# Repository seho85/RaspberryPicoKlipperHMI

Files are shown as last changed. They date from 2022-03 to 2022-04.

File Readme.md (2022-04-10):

>  **DISCLAIMER:**
>   This project project is made by an hobbyist.
>   Everything described here is without guarantee, so if you perform something described here, **YOU DO IT ON YOUR OWN RISK**
>
ASCII Display for Klipper
=========================

This project contains the ASCII Display that I use with Klipper.

It's controlled by a Rotary Encoder and few Buttons and controllable LEDs.

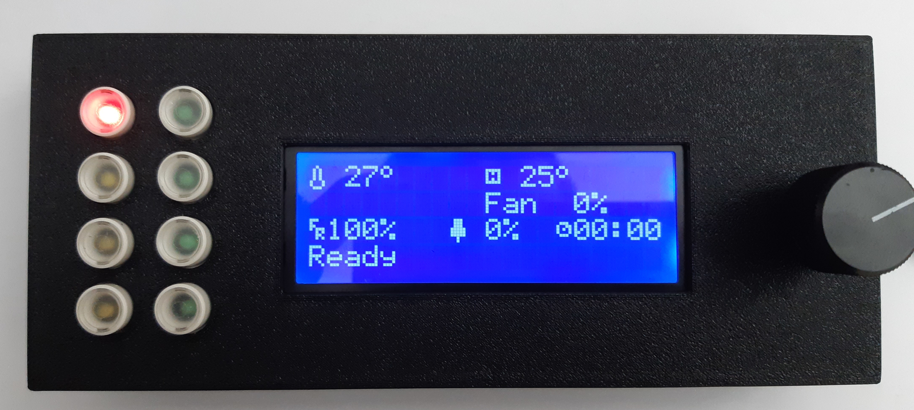
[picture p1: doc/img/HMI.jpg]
HMI


Features:
* Raspberry Pi Pico for easy klipper integration
* 20x4 LCD
  * Controlled by rotary encoder with push button
  * Background LED brightness controllable from klipper
* 8 Pushbuttons for custom actions in klipper
* 7 LEDs triggerable from klipper.
* Single MicroUSB cable for connection to klipper host machine.

See [General](doc/General.md) for details.

KiCAD Projects
--------------
Two KiCAD projects can be found.

* _RPiPicoKlipperAsciiHMI_
  * Schematics I used on my breadboard during "proof of concept" phase.
* _RPiPicoAsciiHMI2_
  * [Schematics](https://github.com/seho85/RaspberryPicoKlipperHMI/raw/master/RPiPicoAsciiHMI2/Schematic.pdf)) for the HMI that I use with klipper.

See [KiCAD Projects](doc/KiCAD_Projects.md)

PCBs
----
Basically the whole HMI consists of two PCBs.

* The [Button PCB](doc/BTN_LED_PCB.md)
    * Buttons (with integrated LEDs)
* The [Main PCB](doc/Main_PCB.md)
  * all other components.

FreeCAD Projects
----------------
In the _FreeCAD_ folder two FreeCAD Projects for the case and the backcover can be found.

Hardware used
-------------
The major components used for the HMI can be found here [Hardware Listing](doc/Hardware.md)

For a complete listing of all the components please refer to the KiCAD Project.

MicroPython
-----------
During the creation process of the HMI I created a few MicroPython scripts to test a components.

See [MicroPython Testing Script](doc/MicroPython.md)

Klipper Configuration
---------------------
See [Klipper Config](doc/klipper_config.md)

How to Flash Raspberry Pi Pico
------------------------------
See [Flashing](doc/Flashing.md)

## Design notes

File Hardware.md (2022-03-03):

Hardware Used
=============

BOM
---
* Potentiometer 10k
* LCD20x04 (HD44780 Compatible)
* Rotary Encoder with Push Button
* RaspberryPi Pico
* diffrent Resistors
* Buttons
* ULN2803A

Where to Buy?
-------------

http://www.berrybase.de

* [Display](https://www.berrybase.de/sensoren-module/displays/alphanumerische-displays/alphanumerisches-lcd-20x4-blau/wei-223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)
* [Raspberry Pi Pico](https://www.berrybase.de/neu/raspberry-pi-pico-rp2040-mikrocontroller-board?number=RPI-PICO&c=2461)
* [ULN2830A](https://www.berrybase.de/bauelemente/aktive-bauelemente/ics/ics-u../uln2803a-npn-darlington-transistor-array-dil-18)
* [Rotary Encoder](https://www.berrybase.de/bauelemente/passive-bauelemente/potentiometer/drehimpulsgeber/drehregler/rotary-encoder-mit-breakoutboard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)
* [Potentiometer](https://www.berrybase.de/bauelemente/passive-bauelemente/potentiometer/drehpotis/drehpotentiometer-10k-937-liegend-mono-6mm-printmontage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)

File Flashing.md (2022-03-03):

How to flash Klipper to Raspberry Pi Pico
=========================================

Build klipper for Raspberry Pi Pico
-----------------------------------
1) Go to klipper directory
2) call _make menuconfig_
3) select
    * Micro-controller Architecture
        * Raspberry PI RP2040
    * Communication Interface
        * USB
    * GPIO Pins to set at micro-controller startup
        * !gpio0,!gpio1,!gpio5,!gpio4,!gpio3,!gpio2
4) save configuration
5) build firmware
    * call _make_
6) file needed for flashing can be found in
    * klipper/out/klipper.uf2

Flash Raspberry Pi Pico
-----------------------
1) Press the _BOOTSEL_ button on the Raspberry Pi Pico, 
2)  connected the USB cable.
    * The RPi Pico will be detected as USB flash device
3) Mount flash device
4) Copy _klipper.uf2_ to RPi Pico Flash Drive.
    * RPi Pico should now automatically perform a reboot and execute downloaded klipper firmware.
5) From now on the RPi Pico Module will be detected as an serial interface. Which can be configured in the klipper configuration.

During my development is created a small script which is placed in the klipper folder to automate the process of mounting, copying and unmounting.

Before executing it be sure that the RPi Pico is available at _/dev/sda1_

```
mkdir -p /tmp/rpi
sudo mount /dev/sda1 /tmp/rpi/
sudo cp out/klipper.uf2 /tmp/rpi/
sudo umount /tmp/rpi
```

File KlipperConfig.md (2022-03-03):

Klipper Configuration
=====================

Patch
-----
Some LCD character displays like mine doesn't work with actual version (v0.10.0-272), they were just utilized to fast on the paralell display interface.

I created a [pull request](https://github.com/Klipper3d/klipper/pull/5318) that delays (which were already defined - but hardcoded) can be configured in the configuration file.
But untils it's not accepted and merged into the codebase of klipper a single file needs to be patched.

Please see the [pull request](https://github.com/Klipper3d/klipper/pull/5318) which tweaks needed to be made. Or to find out if tweaks need to be made at all.

Configuration
-------------
Till the last two parameters in the configuration pretty much everything in configuration is default [klipper display configuration](https://www.klipper3d.org/Config_Reference.html#display-support)

The _hd44780_init_delay_ and _hd44780_pin_delay_ controll the delay for utilizing the paralell interface of the the display.

If your display works, you try to lower the value until not works anymore, to find the delay your actual display needs.

If you see just gibberish output on your display, you may need to increase this delays.

```
[mcu rp_pico]
serial: /dev/serial/by-id/usb-Klipper_rp2040_E6611C08CB077322-if00
baud: 250000

[output_pin pico_led]
pin: rp_pico:gpio25

[output_pin lcd_backlight]
pin: rp_pico:gpio15
pwm: true
cycle_time: 0.010
hardware_pwm: true
value: 1

[display]
lcd_type: hd44780
rs_pin: rp_pico:gpio0
e_pin: rp_pico:gpio1
d4_pin: rp_pico:gpio5
d5_pin: rp_pico:gpio4
d6_pin: rp_pico:gpio3
d7_pin: rp_pico:gpio2
hd44780_protocol_init: True
line_length: 20
menu_timeout: 30

#control button pins (pulled up)
up_pin: ^rp_pico:gpio7
down_pin: ^rp_pico:gpio8
back_pin:^rp_pico:gpio10

#Internal Pulled Up - Low Active
#Dangerous config - no wire break detection
kill_pin: ^!rp_pico:gpio6

# Rotary Encode Module
click_pin: ^rp_pico:gpio9
encoder_pins: rp_pico:gpio11,rp_pico:gpio12

#Attention: Needs Patch
hd44780_init_delay: .200
hd44780_pin_delay: .0004
```

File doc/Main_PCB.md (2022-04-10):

Main PCB
========
The Main PCB contains all parts, except for the push buttons with integrated LED.

I used an Raspberry Pi Pico Module, because there is an existing Firmware Implementation for Klipper which makes the usage very easy.

The DIL-18 IC is an ULN2802A which is used to switch the power over of every controlable peripheral.

LEDs on the ButtonPCB and the Backlight of the LCD Module.

Size
----
* Height
  * 24 Holes
* Width
  * 51 Holes

Top View
--------
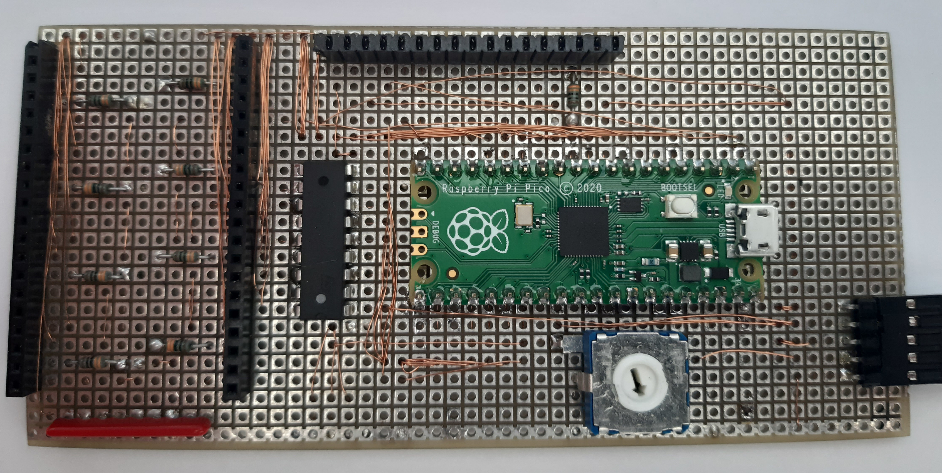
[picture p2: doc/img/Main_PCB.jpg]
Top View


Bottom View
-----------
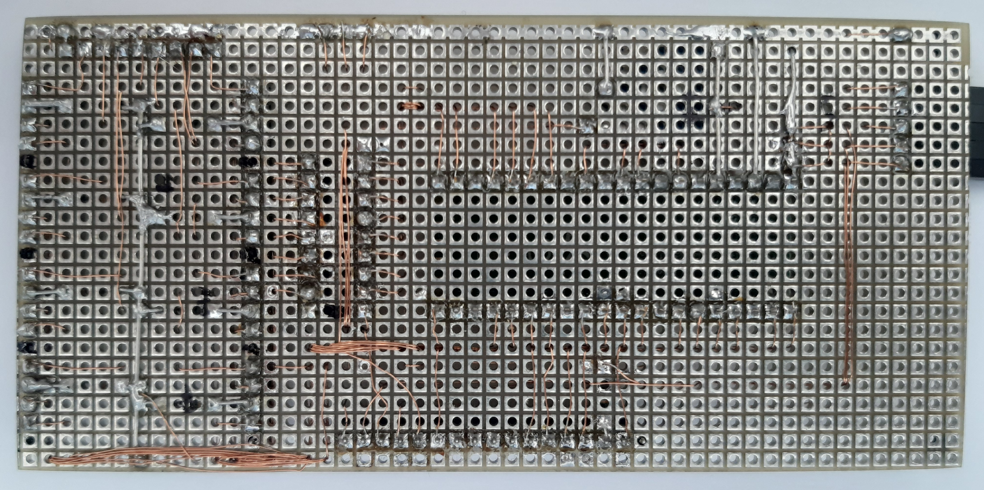
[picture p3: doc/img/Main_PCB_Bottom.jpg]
Bottom View


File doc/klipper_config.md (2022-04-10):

KlipperConfig for HMI
=====================

Here is complete configuration that contains everything that can be used in klipper.

Config Contents
---------------

This config contains the following elements:
* Display configuration for showing the Klipper Menu
  * Display configuration includes the defintions for the rotary encoder to controll the menu.
  * See [Klipper Patch](klipper_patches.md) for usage of the _hd44780_init_delay_ and _hd44780_pin_delay_ parameter.
* _output_pin_ definitions for the LEDs integrated in the buttons
* _gcode_btn_ definitions  for triggering user defined actions.
  * I use BTN1 (the one with allways on red LED) as Emergency Stop

Config
------
For the different sections you can find the documentation in the Klipper Configuration reference.
* [display](https://www.klipper3d.org/Config_Reference.html#display)
* [output_pin](https://www.klipper3d.org/Config_Reference.html#output_pin)
* [gcode_button](https://www.klipper3d.org/Config_Reference.html#gcode_button)
* [menu](https://www.klipper3d.org/Config_Reference.html#menu) for customizing the menu that is shown on pressing the button on the rotary encoder.

```
[mcu rp_pico]
serial: /dev/serial/by-id/usb-Klipper_rp2040_E660C0621359AD30-if00
baud: 250000
restart_method: command

[output_pin lcd_backlight]
pin: rp_pico:gpio28
pwm: true
cycle_time: 0.010
hardware_pwm: true
value: 1

[display]
lcd_type: hd44780
rs_pin: rp_pico:gpio0
e_pin: rp_pico:gpio1
d4_pin: rp_pico:gpio5
d5_pin: rp_pico:gpio4
d6_pin: rp_pico:gpio3
d7_pin: rp_pico:gpio2
hd44780_protocol_init: True
line_length: 20
menu_timeout: 30

# Rotary Encode Module
click_pin: ^rp_pico:gpio22
encoder_pins: rp_pico:gpio26,rp_pico:gpio27

#Attention: Patched Klipper is needed when the two following parameters were used.
hd44780_init_delay: .400
hd44780_pin_delay: .00055

#May be used for testing prints out 01234 on the second row in the second column on the display.
#display_group: static_text_grp

#[display_data static_text_grp static_text1]
#position: 1,1
#text: 01234

############
### LEDs ###

[output_pin btn2_led]
pin: rp_pico:gpio21

[output_pin btn3_led]
pin: rp_pico:gpio20

[output_pin btn4_led]
pin: rp_pico:gpio19

[output_pin btn5_led]
pin: rp_pico:gpio18

[output_pin btn6_led]
pin: rp_pico:gpio17

[output_pin btn7_led]
pin: rp_pico:gpio16

[output_pin btn8_led]
pin: rp_pico:gpio15

###############
### Buttons ###

#Emergency Stop BTN
[gcode_button btn1]
pin: ^!rp_pico:gpio6
press_gcode: M112

[gcode_button btn2]
pin: ^!rp_pico:gpio7
press_gcode: BTN2

[gcode_button btn3]
pin: ^!rp_pico:gpio8
press_gcode: BTN3

[gcode_button btn4]
pin: ^!rp_pico:gpio9
press_gcode: BTN4

[gcode_button btn5]
pin: ^!rp_pico:gpio10
press_gcode: BTN5

[gcode_button btn6]
pin: ^!rp_pico:gpio11
press_gcode: BTN6

[gcode_button btn7]
pin: ^!rp_pico:gpio12
press_gcode: BTN7

[gcode_button btn8]
pin: ^!rp_pico:gpio13
press_gcode: BTN8
```

Delay Parameters
----------------

hd44780_init_delay
------------------
The _hd44780_init_delay_ adds a delay on the intialization phase of the LCD Display, if you use a 4 line display and you see garbage on every 4 lines of the display you most likely **don't** need any tweaks for the settings.

If you 4 lines display just prints out stuff on the first and third line you may need to tweak this setting.

The default value used when setting is not provided is _0.100_ seconds

I you encounter problems that were described above add this too your _[display]_ sections, and increase the value till you got stuff on all 4 lines.

hd44780_pin_delay
-----------------
The _hd44780_pin_delay_ controlles the delay performed when a character is transmitted to the LCD Display.

When your display shows garbage on all 4 lines, you most likely need to tweak this setting.

The default value is 0.00004 sec if parameter is not used.

For finding out the delay for your display, add the configuration option and set it to _0.004_

When the display shows correct output try to lower the setting by factor ten, until you just got garbage printed out. Then increase the delay until you got reliable and good printings on your display.

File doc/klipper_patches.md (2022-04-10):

Klipper Patches
===============
The LCD Module may need some tweaks in the klipper sourcecode to work properly.

You can find out easily if you need this patches.

When your display just show garbage, the you need this patch.

I created this patch and also created a pull request that this changes can be merged into the main klipper source.

Unfortunately integrating this changes is currently denied, because there are not at least 100 people that would benified from the changes.

**So please, if you encounter this problem add a comment to my [pull request](https://github.com/Klipper3d/klipper/pull/5318)**

You can patch your own sourcetree with the patch provided below or just take the whole [hd44780.py](https://raw.githubusercontent.com/seho85/klipper/master/klippy/extras/display/hd44780.py) file from my klipper fork, that integrates that changes.

What does the patch provide
---------------------------
If your display just shows garbage it's most likely cost by the strict timings that were used to controll the LCD per it's paralell interface.

The Patch gives you the opportunity to lower this strict timings.

Patch
-----
```
klippy/extras/display/hd44780.py

@@ -12,8 +12,6 @@

TextGlyphs = { 'right_arrow': b'\x7e' }

HD44780_DELAY = .000040

class HD44780:
    def __init__(self, config):
        self.printer = config.get_printer()
@@ -48,13 +46,17 @@ def __init__(self, config):
             0xc0),
            # Glyph framebuffer
            (self.glyph_framebuffer, bytearray(b'~'*64), 0x40) ]
        self.initialization_delay = config.getfloat("hd44780_init_delay",
            .100, .100, 1.0)
        self.display_pin_delay = config.getfloat("hd44780_pin_delay", .00004,
            .00004, 1.0)
    def build_config(self):
        self.mcu.add_config_cmd(
            "config_hd44780 oid=%d rs_pin=%s e_pin=%s"
            " d4_pin=%s d5_pin=%s d6_pin=%s d7_pin=%s delay_ticks=%d" % (
                self.oid, self.pins[0], self.pins[1],
                self.pins[2], self.pins[3], self.pins[4], self.pins[5],
                self.mcu.seconds_to_clock(HD44780_DELAY)))
                self.mcu.seconds_to_clock(self.display_pin_delay)))
        cmd_queue = self.mcu.alloc_command_queue()
        self.send_cmds_cmd = self.mcu.lookup_command(
            "hd44780_send_cmds oid=%c cmds=%*s", cq=cmd_queue)
@@ -98,7 +100,8 @@ def init(self):
        # Reset (set positive direction ; enable display and hide cursor)
        init.append([0x06, 0x0c])
        for i, cmds in enumerate(init):
            minclock = self.mcu.print_time_to_clock(print_time + i * .100)
            minclock = self.mcu.print_time_to_clock(
                print_time + i * self.initialization_delay)
            self.send_cmds_cmd.send([self.oid, cmds], minclock=minclock)
        self.flush()
    def write_text(self, x, y, data):
```

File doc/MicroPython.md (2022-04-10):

MicroPython Testscripts
=======================
The Raspberry Pico Module can be programmed in MicroPython, which makes it handy for testing different components of the HMI.

Describing the whole process of setting up everything is beyond the scope of this description.

Here are a few links to get started with MicroPython on the PI Pico.

* https://www.raspberrypi.com/documentation/microcontrollers/micropython.html
* https://dev.to/blues/your-first-steps-with-raspberry-pi-pico-and-visual-studio-code-4jbd
* https://marketplace.visualstudio.com/items?itemName=ChrisWood.pico-go

This links should point you in the right direction to get the following testing scripts running. Which I heavily recommend for testing you soldering after checking the connections with an multimeter.

Also I know the scripts weren't very pretty, but the were hacked quick and dirty during the soldering session.

Buttons Test
------------
If this script is running on the Pi Pico, it creates an output when a button is pressed.

It can be used testing the connection of all the buttons.

Don't wonder if the message is printed more then once on a button press, this because the buttons are not debounced.

```
from machine import Pin
import machine
import time

btn1 = machine.Pin(6, Pin.IN, Pin.PULL_UP)
btn2 = machine.Pin(7, Pin.IN, Pin.PULL_UP)
btn3 = machine.Pin(8, Pin.IN, Pin.PULL_UP)
btn4 = machine.Pin(9, Pin.IN, Pin.PULL_UP)
btn5 = machine.Pin(10, Pin.IN, Pin.PULL_UP)
btn6 = machine.Pin(11, Pin.IN, Pin.PULL_UP)
btn7 = machine.Pin(12, Pin.IN, Pin.PULL_UP)
btn8 = machine.Pin(13, Pin.IN, Pin.PULL_UP)

def button_handler(pin):
    print("Button " + str(pin))
    time.sleep_ms(100)

btn1.irq(trigger=Pin.IRQ_FALLING, handler=button_handler)
btn2.irq(trigger=Pin.IRQ_FALLING, handler=button_handler)
btn3.irq(trigger=Pin.IRQ_FALLING, handler=button_handler)
btn4.irq(trigger=Pin.IRQ_FALLING, handler=button_handler)
btn5.irq(trigger=Pin.IRQ_FALLING, handler=button_handler)
btn6.irq(trigger=Pin.IRQ_FALLING, handler=button_handler)
btn7.irq(trigger=Pin.IRQ_FALLING, handler=button_handler)
btn8.irq(trigger=Pin.IRQ_FALLING, handler=button_handler)
```

LED Test
--------
This script toggles trough all the controllable LEDs integrated in buttons.

```
from machine import Pin
import machine
import time

led2 = machine.Pin(21, Pin.OUT)
led3 = machine.Pin(20,  Pin.OUT)
led4 = machine.Pin(19,  Pin.OUT)
led5 = machine.Pin(18,  Pin.OUT)
led6 = machine.Pin(17,  Pin.OUT)
led7 = machine.Pin(16,  Pin.OUT)
led8 = machine.Pin(15,  Pin.OUT)

leds = [ led2, led3, led3, led4, led5, led6, led7, led8]

for led in leds:
    led.high()
    time.sleep(1)
    led.low()
```

LCD Test
--------
To verifiy if the LCD is connected properly this script can be used.

It initializes the display and shows _000_ on the Display.

```
from machine import Pin
import time

bg = Pin(28, Pin.OUT, Pin.PULL_DOWN)

rs = Pin(0, Pin.OUT, Pin.PULL_DOWN)
e = Pin(1, Pin.OUT, Pin.PULL_DOWN)

d7 = Pin(2, Pin.OUT, Pin.PULL_DOWN)
d6 = Pin(3, Pin.OUT, Pin.PULL_DOWN)
d5 = Pin(4, Pin.OUT, Pin.PULL_DOWN)
d4 = Pin(5, Pin.OUT, Pin.PULL_DOWN)

def pulse():
    e.low()
    time.sleep_us(100);
    e.high()

def all_data_low():
    d7.low()
    d6.low()
    d5.low()
    d4.low()

#initial state
bg.high()

e.high()
rs.low()

all_data_low()

print("Waiting 10 seconds...\n");
#time.sleep(10)

time.sleep_ms(500)

d4.high()
d5.high()
pulse()

time.sleep_ms(10)
pulse()

time.sleep_ms(1)
d4.low()
pulse()

# display setup
d7.low()
d6.low()
d5.high()
d4.low()
pulse()
time.sleep_ms(1)

d7.high()
d6.low()
pulse()

time.sleep_ms(1)

#display off
d7.low()
d6.low()
d5.low()
d4.low()
pulse()

d7.high()
pulse()

# display on
all_data_low()
pulse()
time.sleep_us(100)

d7.high()
d6.high()
pulse()
time.sleep_us(100)

#print zero
rs.high()
all_data_low()
d4.high()
d5.high()
pulse()
time.sleep_us(100)
all_data_low()
pulse()
time.sleep_us(100)

all_data_low()
d4.high()
d5.high()
pulse()
time.sleep_us(100)
all_data_low()
pulse()
time.sleep_us(100)

all_data_low()
d4.high()
d5.high()
pulse()
time.sleep_us(100)
all_data_low()
pulse()
time.sleep_us(100)
```

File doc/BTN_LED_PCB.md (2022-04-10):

Button + LED PCB
================

The push buttons with integrated LEDs are placed on a seperate PCB which is connected as piggy back ciricute board to main board.

I used a stripboard with a pitch of 2.54mm (0.1inch) stripe layout for that.

The copper layers were divided in half by using a 4mm drill.

* Width 
  * 13 Holes
* Height
  * 23 Holes

Top
---

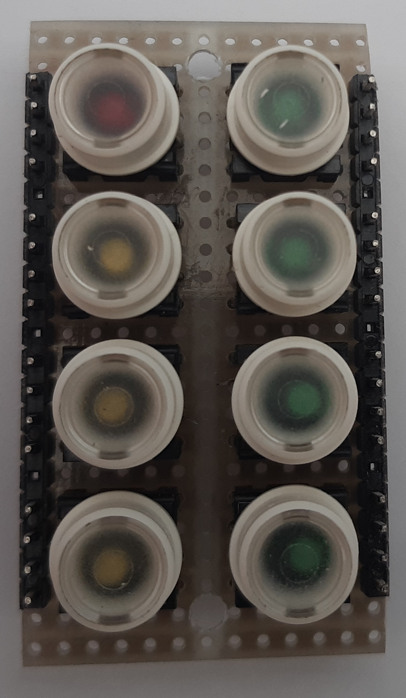
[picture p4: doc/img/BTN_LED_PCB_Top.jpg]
Top


Bottom
------

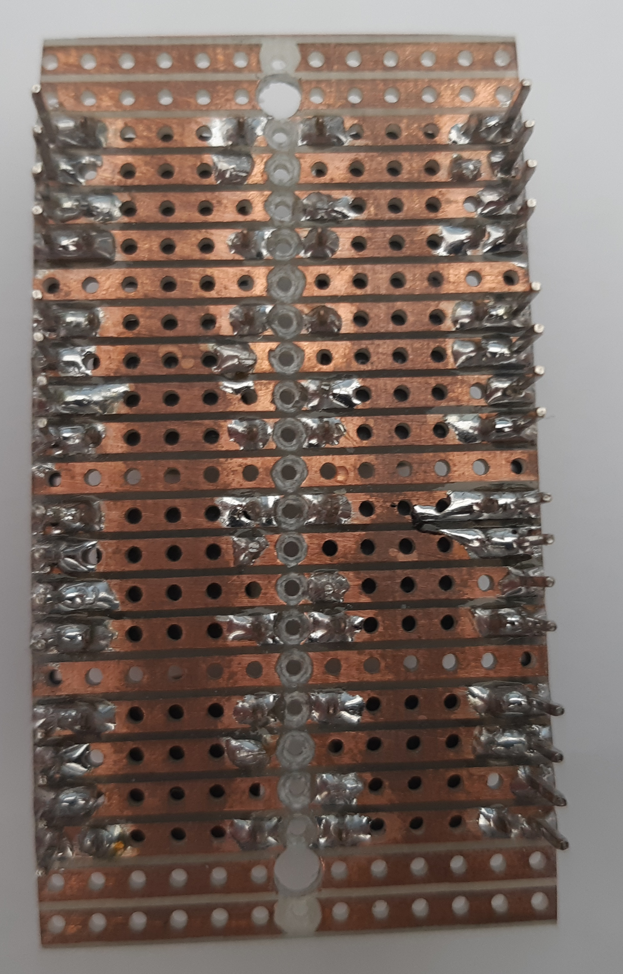
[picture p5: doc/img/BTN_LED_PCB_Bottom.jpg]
Bottom


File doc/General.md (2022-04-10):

General
=======
Goal of this project was to make an HMI for controlling klipper.

Goals:
* Easy integration into Klipper
* Only one cable to the device that runs klipper (e.G. Raspberry PI).
* Having a hardware "Emergency Stop" Button.

Using:
* 4x20 Character LCD (HD44780)
* 8 Buttons that can be used in Klipper to perform any defined action.
* 7 LEDs that can also be individually controlled from Klipper.
* Rotary encoder with push button for controlling the menu.

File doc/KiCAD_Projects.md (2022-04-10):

KiCad Projects
==============
Two KiCad Projects were included here:

* RPIPicoAsciHMI2
  * The Project for the Display that i use with klipper on my printer
* RPiPicoKlipperAsciiHMI
  * The project where i started from (runned on a breadboard)

**WARNING: 
The Pins used in the KiCAD projects are not the same!**

For details how the PCB are connected please refer to the KiCad Projects.

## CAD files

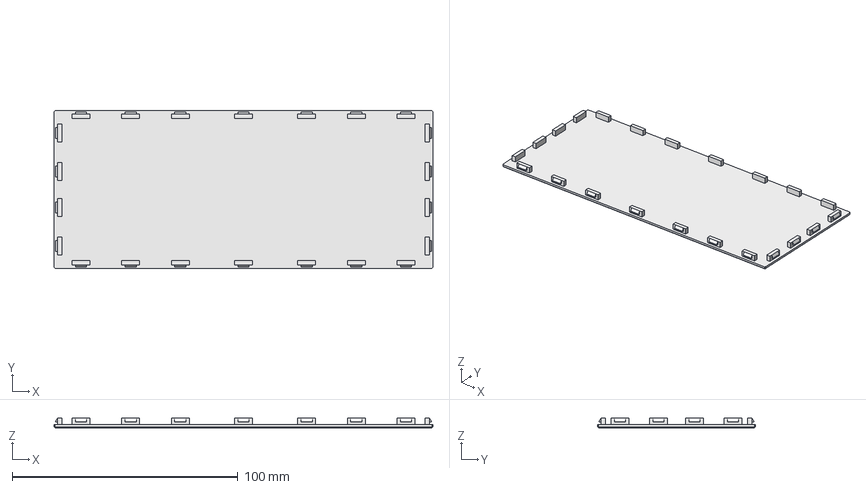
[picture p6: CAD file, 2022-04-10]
FreeCAD/Cover.FCStd
168.0 x 70.0 x 4.50 mm

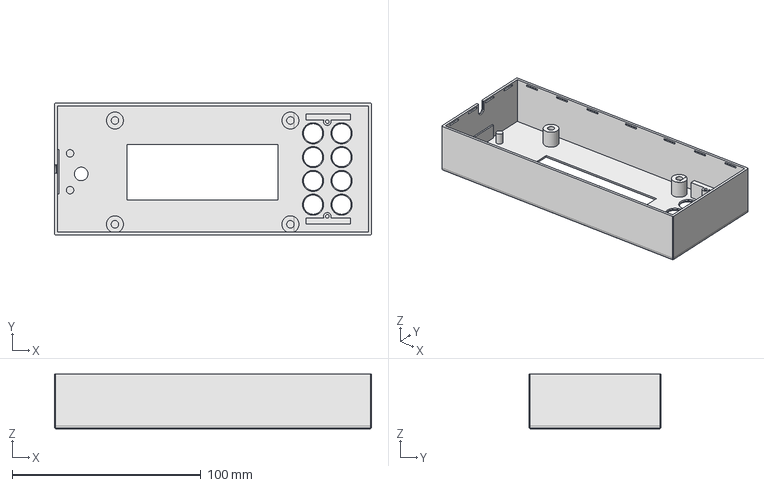
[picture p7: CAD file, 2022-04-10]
FreeCAD/Case.FCStd
168.0 x 70.0 x 29.0 mm

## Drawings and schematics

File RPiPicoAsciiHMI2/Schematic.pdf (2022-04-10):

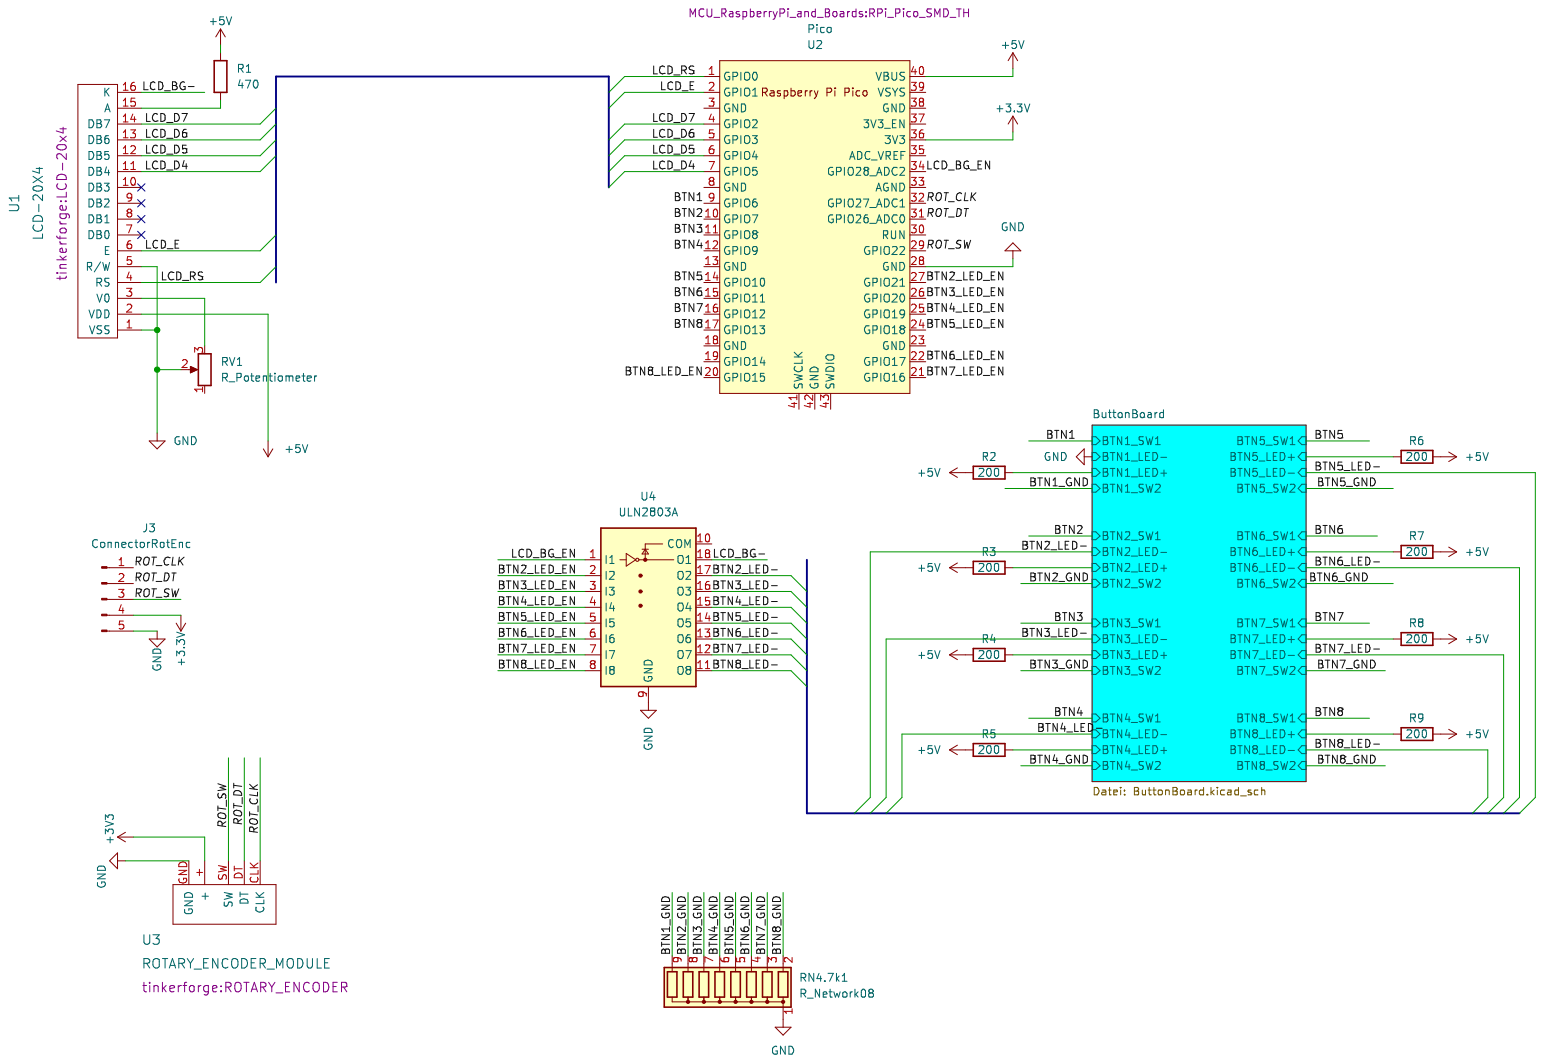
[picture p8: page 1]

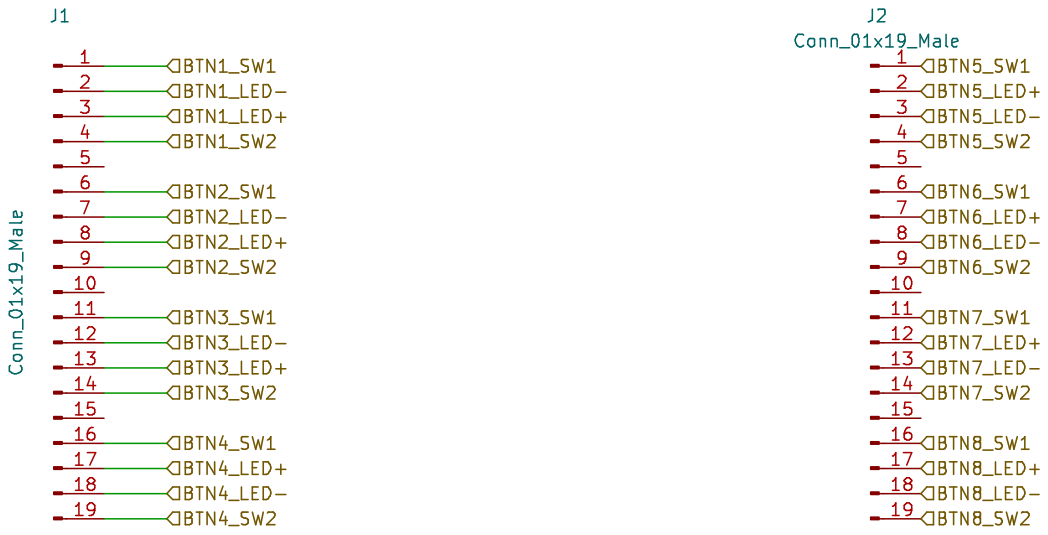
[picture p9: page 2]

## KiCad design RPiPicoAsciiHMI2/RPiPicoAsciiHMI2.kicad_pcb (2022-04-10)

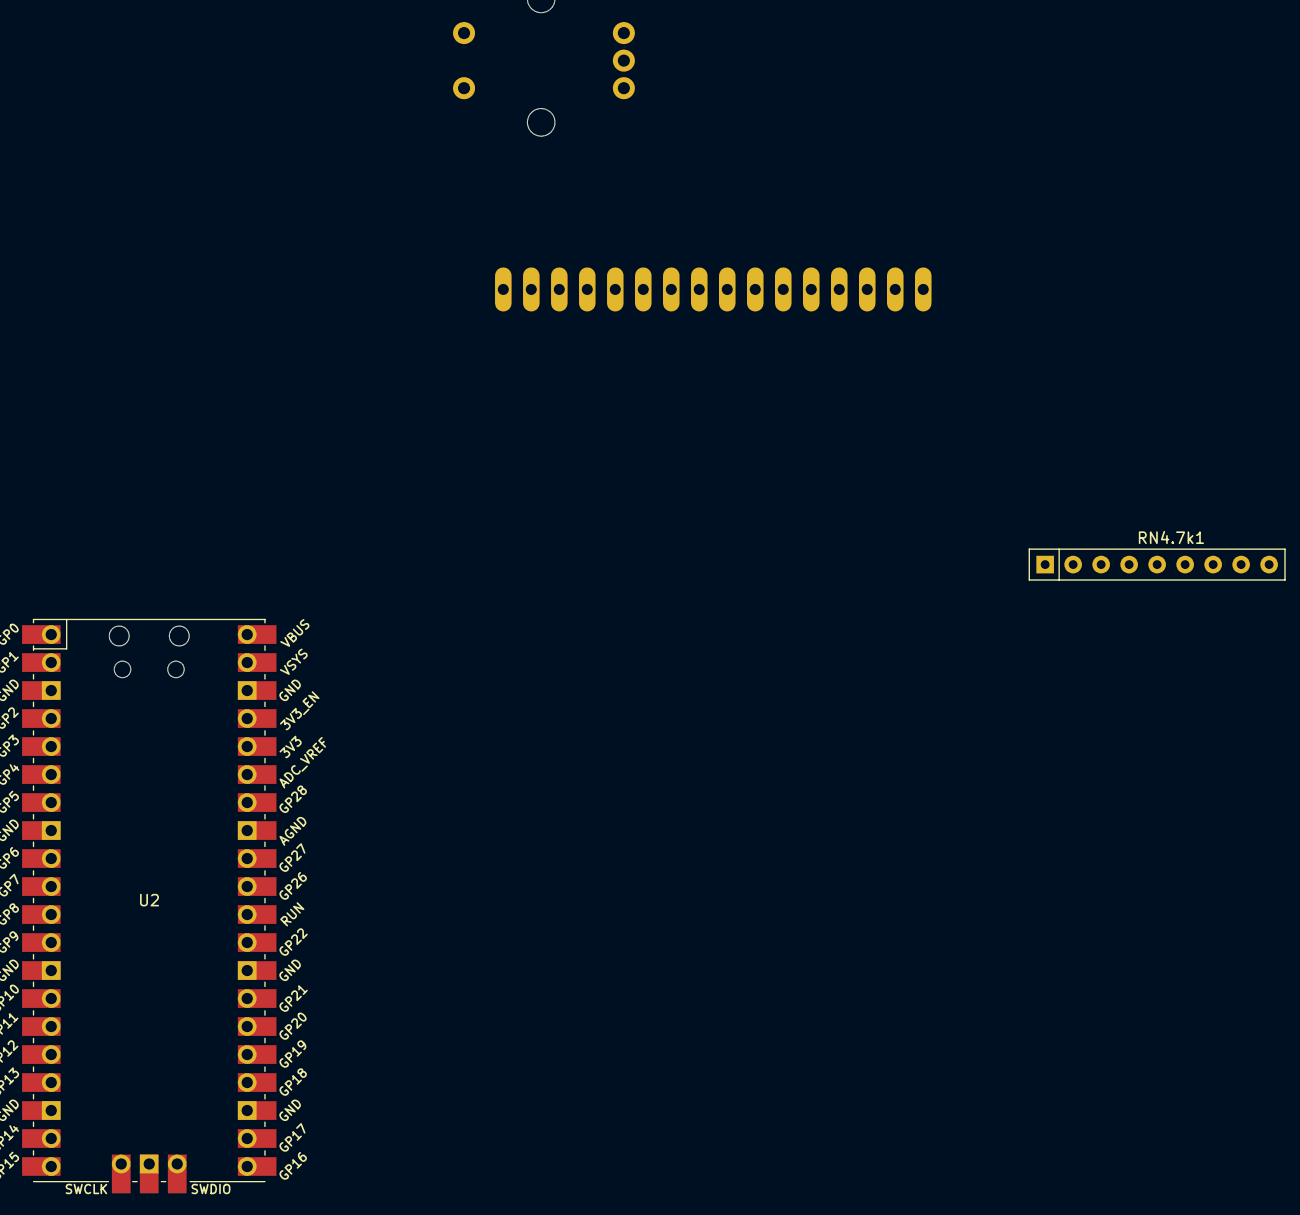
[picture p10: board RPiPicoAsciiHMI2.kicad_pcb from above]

Board: 2 copper layers, 4 parts (0 on the bottom side), 2 nets, no tracks yet.

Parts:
RN4.7k1: R_Network08; R_Array_SIP9
U1: LCD-20X4; LCD-20x4
U2: Pico; RPi_Pico_SMD_TH
U3: ROTARY_ENCODER_MODULE; ROTARY_ENCODER

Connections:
+5V: U1.2 (VDD), U2.40 (VBUS)
GND: U1.1 (VSS), U1.5 (R/W), U2.28 (GND)

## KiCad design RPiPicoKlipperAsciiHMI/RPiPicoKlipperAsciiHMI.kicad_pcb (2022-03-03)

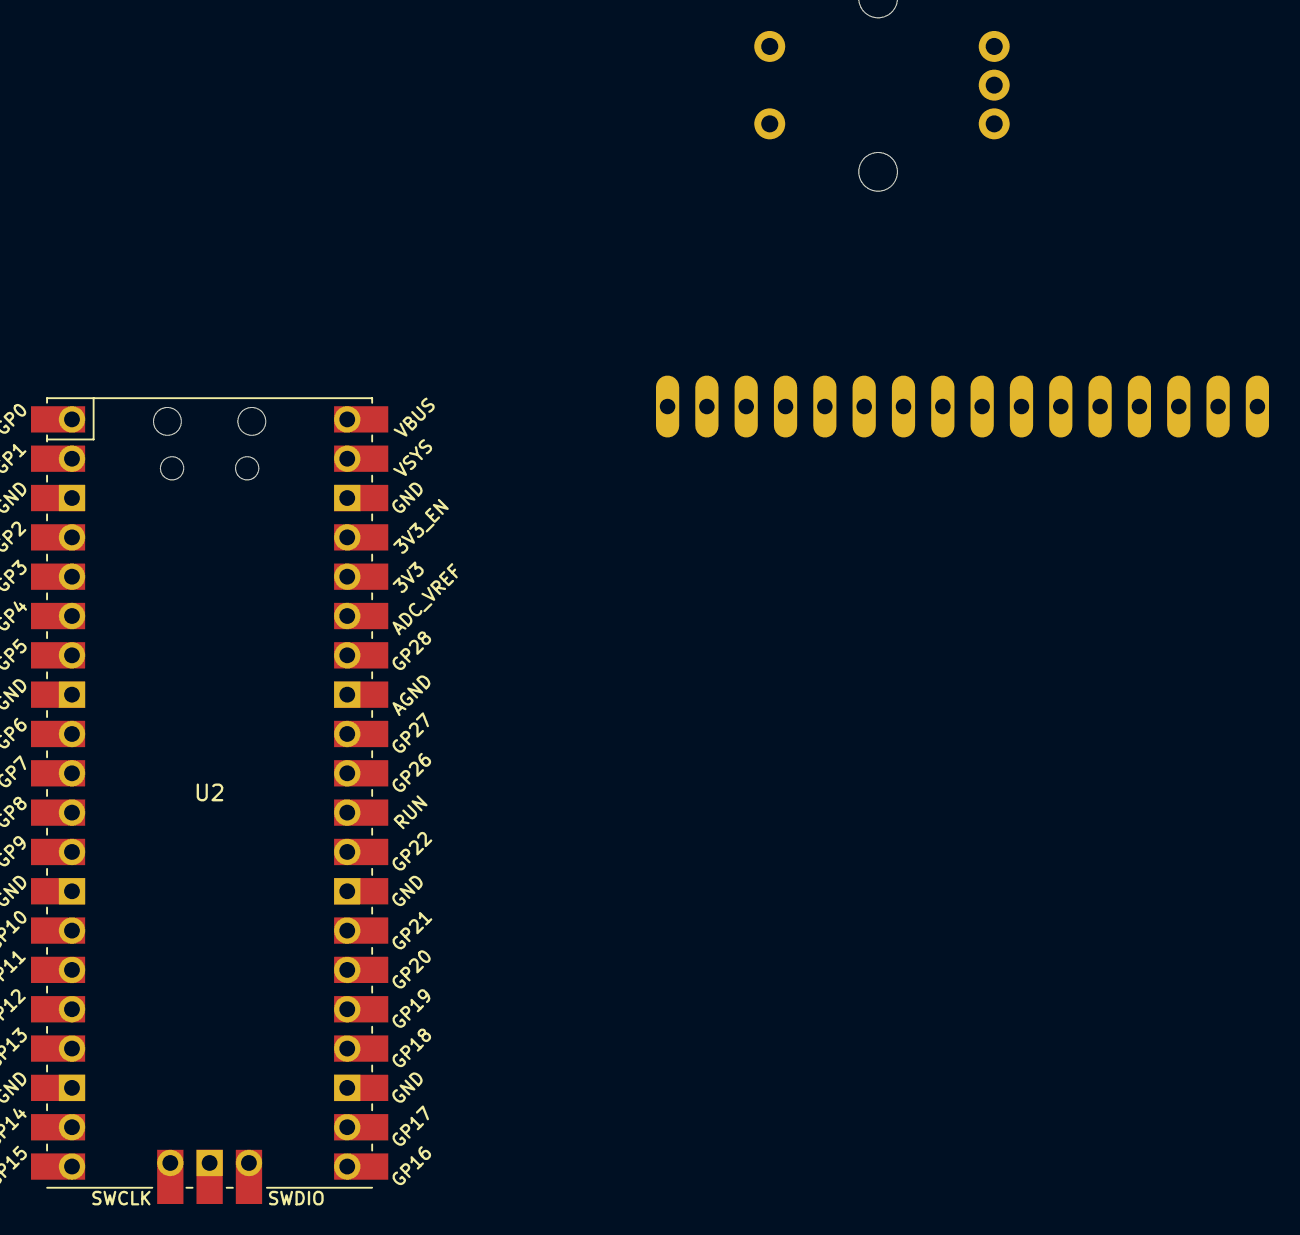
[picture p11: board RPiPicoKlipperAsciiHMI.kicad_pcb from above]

Board: 2 copper layers, 3 parts (0 on the bottom side), 8 nets, no tracks yet.

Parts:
U1: LCD-20X4; LCD-20x4
U2: Pico; RPi_Pico_SMD_TH
U3: ROTARY_ENCODER_MODULE; ROTARY_ENCODER

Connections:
+5V: U1.2 (VDD), U2.40 (VBUS)
/LCD_D4: U1.11 (DB4), U2.7 (GPIO5)
/LCD_D5: U1.12 (DB5), U2.6 (GPIO4)
/LCD_D6: U1.13 (DB6), U2.5 (GPIO3)
/LCD_D7: U1.14 (DB7), U2.4 (GPIO2)
/LCD_E: U1.6 (E), U2.2 (GPIO1)
/LCD_RS: U1.4 (RS), U2.1 (GPIO0)
GND: U1.1 (VSS), U1.5 (R/W), U2.39 (VSYS)

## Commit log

2022-03-03 Initial commit.
    Revision 1 of the KiCAD project and some documentation.
    [RPiPicoKlipperAsciiHMI.kicad_pcb, RPiPicoKlipperAsciiHMI.kicad_sch]
2022-03-03 added link to schematic
2022-04-09 Begun documentation
    Created pages for General, MainPCB and ButtonPCB
    Also added a few pictures of the PCBs.
2022-04-10 Added FreeCAD Projects for Case and Cover
    Added case for the HMI and the cover.
    [Case.FCStd, Cover.FCStd]
2022-04-10 Added KiCAD Project of HMI
    Added the KiCAD project for the HMI that is actually used by me.
    [ButtonBoard.kicad_sch, RPiPicoAsciiHMI2.kicad_pcb, RPiPicoAsciiHMI2.kicad_sch]
2022-04-10 Added latest Version of POC KiCAD Project
    [ButtonBoard.kicad_sch, RPiPicoKlipperAsciiHMI.kicad_sch]
2022-04-10 Removed old schematics.pdf
2022-04-10 Updated Readme.md
    fixed link to schematics.pdf file.
